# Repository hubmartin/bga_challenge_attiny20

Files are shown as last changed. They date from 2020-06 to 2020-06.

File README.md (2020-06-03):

# BGA Challenge

I wanted to improve my assembly and "cutting-edge" PCB pool technical size limits so I've designed this board in KiCAD. It's just 20 x 15 mm PCB.

Board was made with Aisler. Here is the [sharing link](https://aisler.net/p/JWEQJIAC) if you would like to manufacture PCB and stencil.

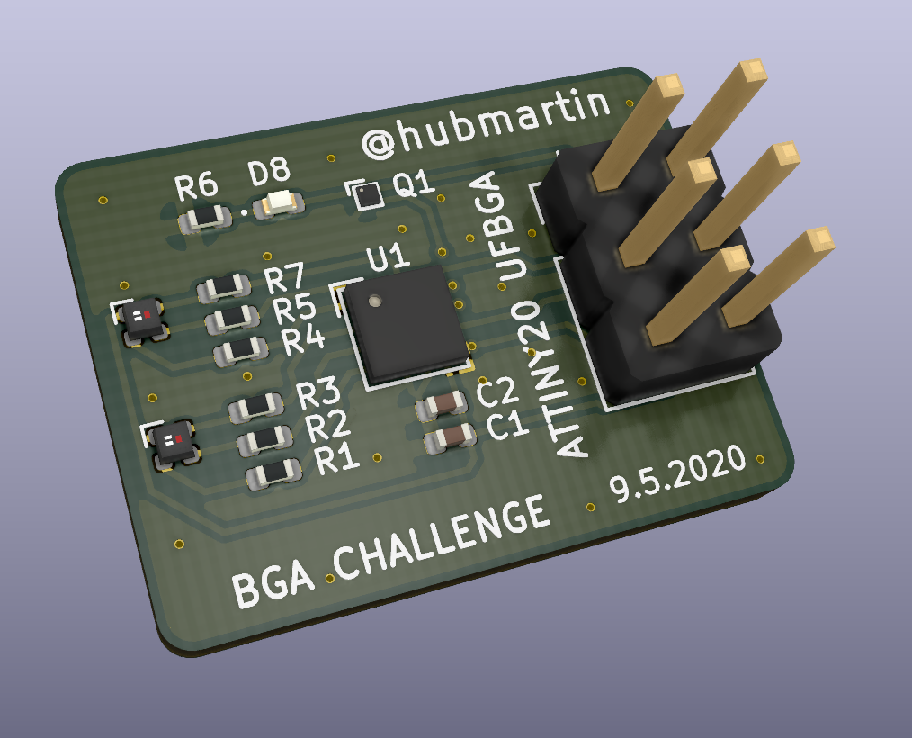
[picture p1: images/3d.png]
3D view

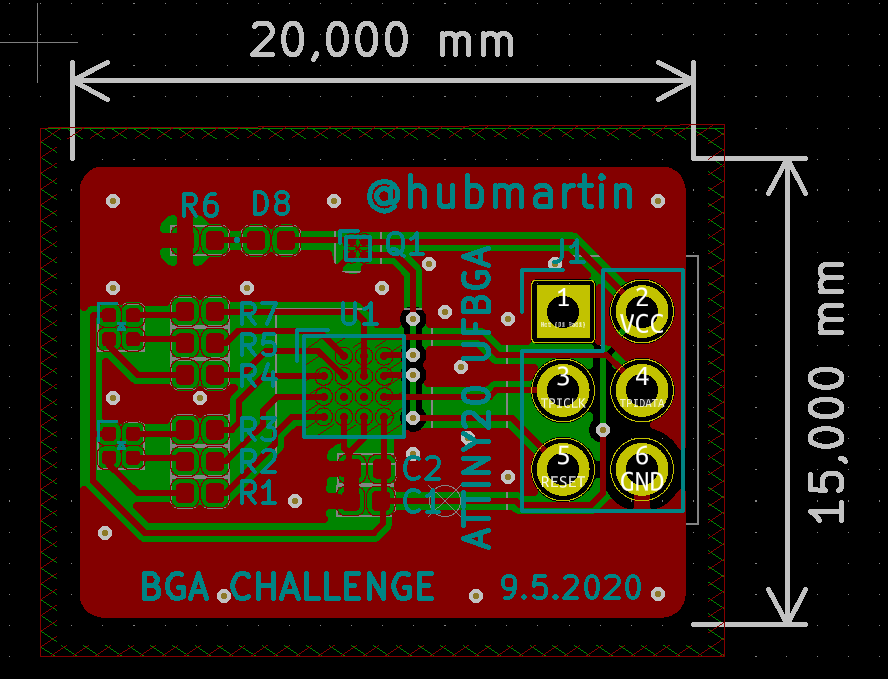
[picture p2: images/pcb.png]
PCB

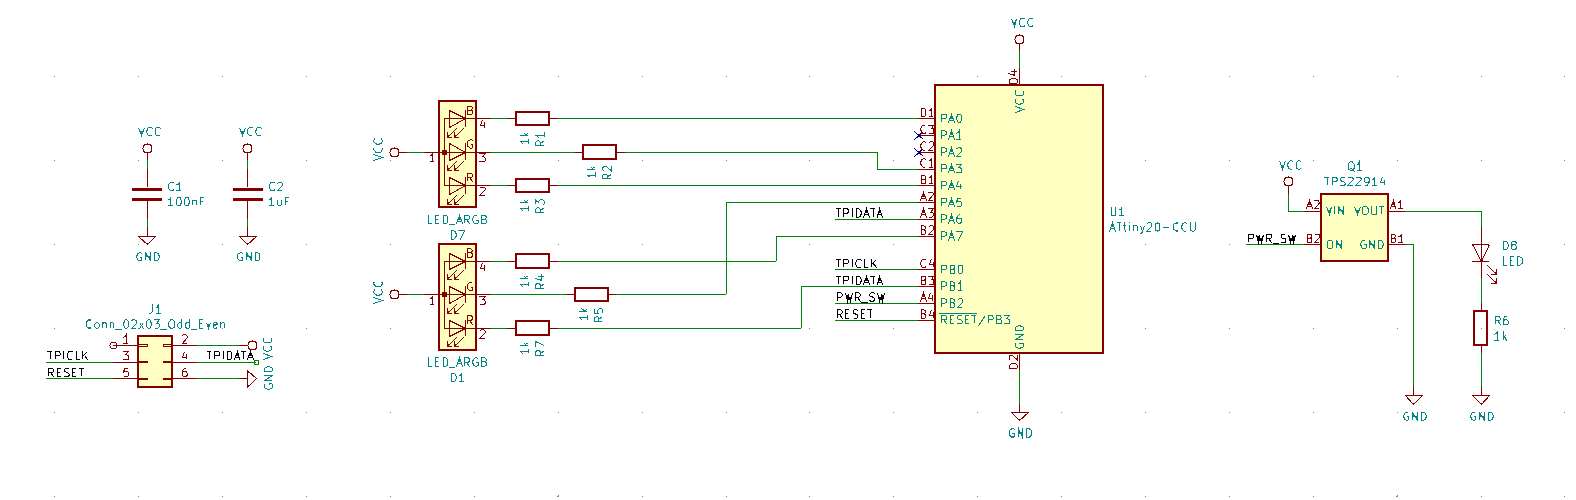
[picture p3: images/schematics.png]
Schematics


More info and pictures in these tweets:
- https://twitter.com/hubmartin/status/1266421947304476685
- https://twitter.com/hubmartin/status/1251945517552144384

# ATTiny20 programming

This board is using 6 pin programmer. ATTiny20 is using TPI programming (instead of ISP) where MOSI pin is bi-directional. You can use [USBasp  programmer by Thomas Fischl](https://www.fischl.de/usbasp/), make sure you have the latest version of firmware with TPI support `usbasp.2011-05-28`. I've read that chinese clones use older firmwares (11 years).

You can also use Arduino to program chip. [Bitluni has a great video about it.](https://www.youtube.com/watch?v=AL9vK_xMt4E)

# Example code

The example code is just blinking to test that you soldered everything right. The power-switch is not controlled yet, as I did not managed to solder this 2x2 BGA correctly yet.

You compile firmware with `build.sh` and flash it with `flash.sh`. Other scripts are for ATtiny204 but that's a different project.

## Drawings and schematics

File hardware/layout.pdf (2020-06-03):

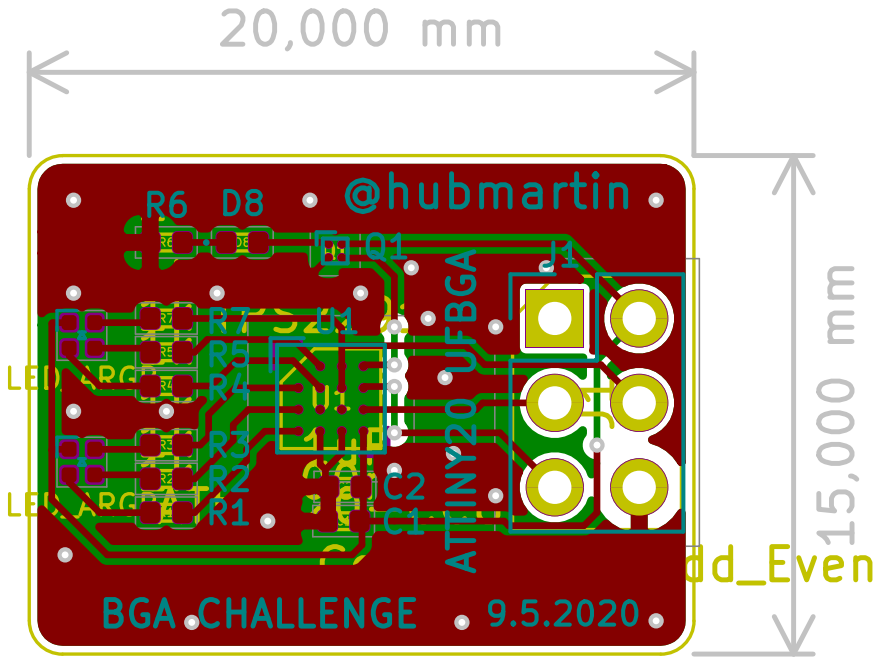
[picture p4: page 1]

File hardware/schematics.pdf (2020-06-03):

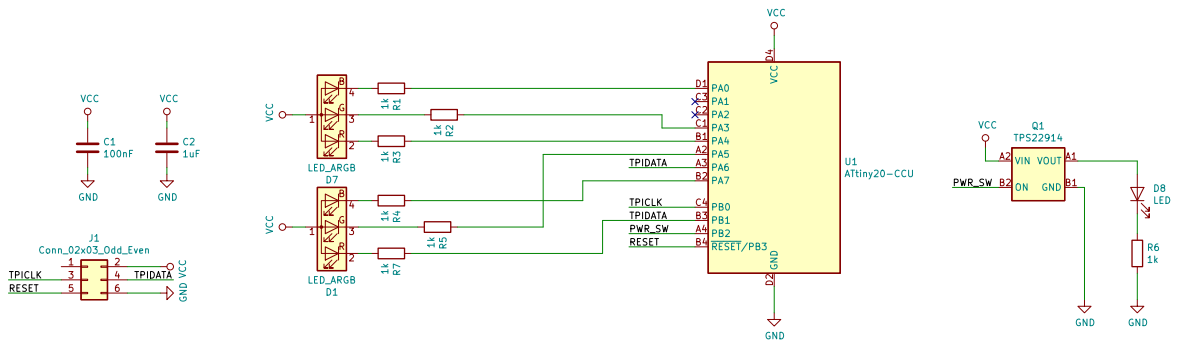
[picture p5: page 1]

Id: 1/1 Title: BGA Challenge

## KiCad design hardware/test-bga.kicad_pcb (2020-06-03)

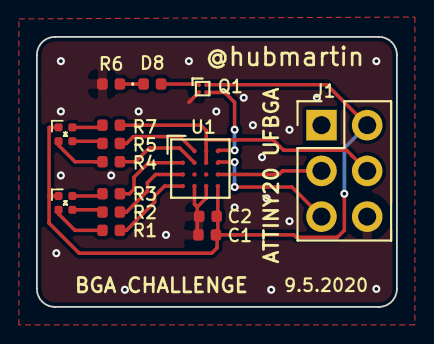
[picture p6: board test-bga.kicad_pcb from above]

Board: 2 copper layers, 20.0 x 15.0 mm, 15 parts (0 on the bottom side), 19 nets.

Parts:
C1: 100nF; C_0402_1005Metric
C2: 1uF; C_0402_1005Metric
D1, D7: LED_ARGB; LED_TRI_1010
D8: LED; LED_0402_1005Metric
J1: Conn_02x03_Odd_Even; PinHeader_2x03_P2.54mm_Vertical
Q1: TPS22914; BGA-4_0.7x0.7mm_Layout2x2_P0.4mm
R1, R2, R3, R4, R5, R6, R7: 1k; R_0402_1005Metric
U1: ATtiny20-CCU; UFBGA-15_3.0x3.0mm_Layout4x4_P0.65mm

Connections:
/PWR_SW: Q1.B2, U1.A4
/RESET: J1.5, U1.B4
/TPICLK: J1.3, U1.C4
/TPIDATA: J1.4, R7.1, U1.A3, U1.B3
GND: C1.2, C2.2, J1.6, Q1.B1, R6.2, U1.D2, U1.D3
unnamed: D1.2, R7.2
unnamed: D1.3, R5.2
unnamed: D1.4, R4.2
unnamed: D7.2, R3.2
unnamed: D7.3, R2.2
unnamed: D7.4, R1.2
unnamed: D8.1, R6.1
unnamed: D8.2, Q1.A1
unnamed: R1.1, U1.D1
unnamed: R2.1, U1.C1
unnamed: R3.1, U1.B1
unnamed: R4.1, U1.B2
unnamed: R5.1, U1.A2
VCC: C1.1, C2.1, D1.1, D7.1, J1.2, Q1.A2, U1.D4

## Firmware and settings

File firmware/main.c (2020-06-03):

#ifndef F_CPU
#define F_CPU 1000000UL // or whatever may be your frequency
#endif
 
#include <avr/io.h>
#include <util/delay.h>                // for _delay_ms()

/*
RGB top 
PA4
PA3
PA0

RGB bottom
PA6
PA5
PA7

*/

int main(void)
{
    DDRA = 0xFF;

    while(1)
    {
        PORTA = ~(1 << 4);
        _delay_ms(500);
        PORTA = ~(1 << 3);
        _delay_ms(500);
        PORTA = ~(1 << 0);
        _delay_ms(500);

        PORTA = ~(1 << 6);
        _delay_ms(500);
        PORTA = ~(1 << 5);
        _delay_ms(500);
        PORTA = ~(1 << 7);
        _delay_ms(500);

    }
}
